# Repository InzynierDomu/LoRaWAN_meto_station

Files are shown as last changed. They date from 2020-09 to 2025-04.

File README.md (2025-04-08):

# LoRaWAN meteo station







- [LoRaWAN meto station](#lorawan-meto-station)
  - [About](#about)
  - [Scheme](#scheme)
    - [Part list:](#part-list)
  - [Configuration](#configuration)
  - [IDE](#ide)
  - [Software upload](#software-upload)

## About
End device to measure air temperature, humidity, pressure, and light intense, and send to TTN. More information for this project you will find in this [note](http://www.inzynierdomu.pl/lora-i-lorawan-czesc-3/)

<div align="center">
<h2>Support</h2>

<p>If any of my projects have helped you in your work, studies, or simply made your day better, you can buy me a coffee. <a href="https://buycoffee.to/inzynier-domu" target="_blank">Postaw mi kawę na buycoffee.to</a></p>
</div>

## Scheme

### Part list:
* U1 Arduino MKR 1300
To board must be connected BME280 and DS18B20. 
## Configuration
Before config this project, prepare an account on TheThingsNetwor. All described [here](http://www.inzynierdomu.pl/lora-i-lorawan-czesc-2/)
Need add device on TTN console to get credentials. Put necessary keys in Config.h file.
To decode information, on TTN use JS formatter ttn_decoder.js.
## IDE
The project is prepared for the Platform IO environment. A video on how to install such an environment can be watched on this [video](https://youtu.be/Em9NuebT2Kc)
## Software upload 
The board may not be programmable during sleep. You should then press the reset button on the board twice quickly. It should appear on a different port and can be programmed.

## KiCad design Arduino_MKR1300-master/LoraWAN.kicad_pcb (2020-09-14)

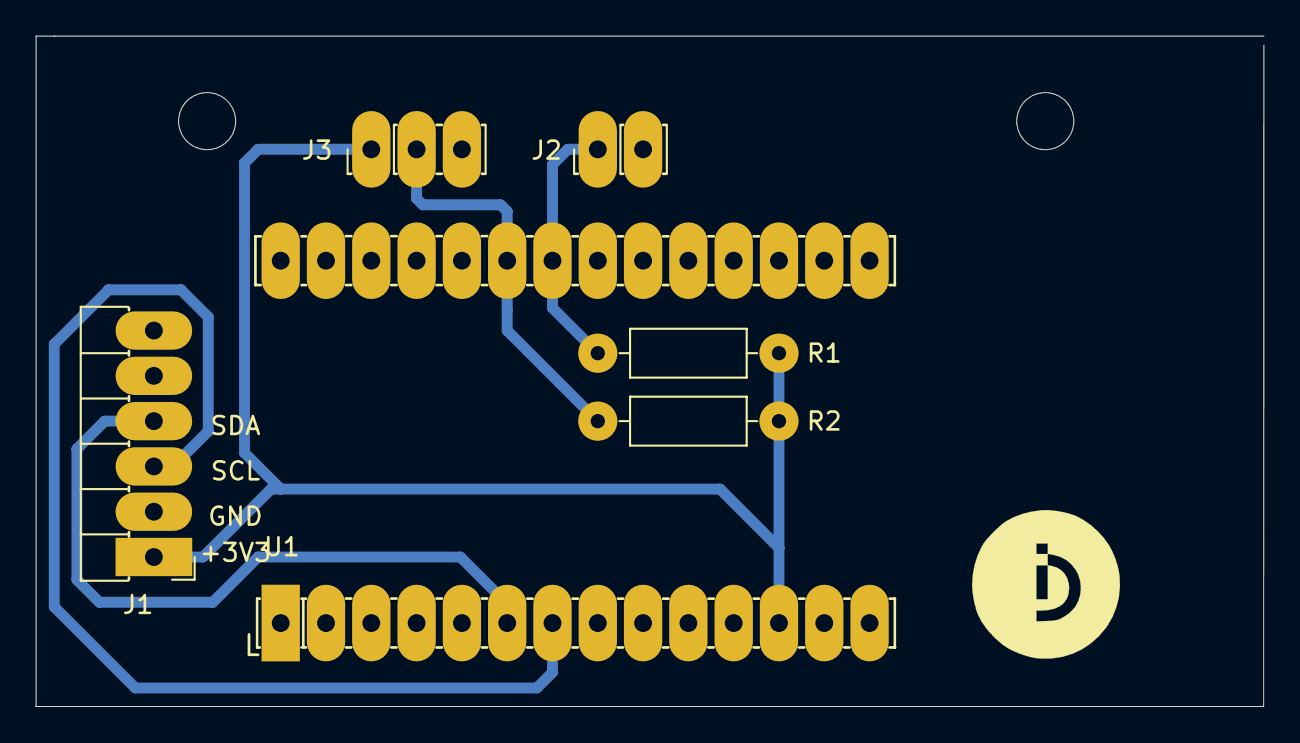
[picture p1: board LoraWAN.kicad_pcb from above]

Board: 2 copper layers, 68.8 x 37.6 mm, 6 parts (0 on the bottom side), 6 nets.

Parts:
J1: Conn_01x06_Male; PinHeader_1x06_P2.54mm_Horizontal_Oval_NoPinSilk
J2: Conn_01x02_Male; PinHeader_1x02_P2.54mm_Vertical_PAD
J3: Conn_01x03_Male; PinHeader_1x03_P2.54mm_Vertical_PAD
R1, R2: 10k; R_Axial_DIN0207_L6.3mm_D2.5mm_P10.16mm_Horizontal_PAD
U1: Ardiuno_MKR1300; Arduino_MKR1300_Oval

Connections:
GND: J1.2, J2.2, J3.3, U1.11
unnamed: J2.1, R1.2, U1.22
unnamed: J3.2, R2.2, U1.23
SCL: J1.3, U1.7
SDA: J1.4, U1.6
VCC: J1.1, J3.1, R1.1, R2.1, U1.12

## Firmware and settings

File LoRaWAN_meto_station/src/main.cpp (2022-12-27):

/**
 * @file LoRaWAN_meteo_station.ino
 * @brief LoRaWAN meteo station main
 * @author by Szymon Markiewicz
 * @details http://www.inzynierdomu.pl/
 * @date 11-2019
 */

#include "ArduinoLowPower.h"
#include "Config.h"
#include "LoRaWAN.h"
#include "Measurements.h"
#include "Pin_config.h"
#include "Results.h"

#include <Arduino.h>

Measurements m_measurements;
LoRaWAN m_lorawan;
Results m_results;

void setup()
{
  Serial.begin(9600);
  delay(60000); // TODO: test without this

  m_lorawan.setup();
  m_measurements.init_sensors();
}

void loop()
{
  m_measurements.measure(m_results);
  m_lorawan.send_msg_measurements(m_results);
  LowPower.deepSleep(Config::uplink_interval);
}

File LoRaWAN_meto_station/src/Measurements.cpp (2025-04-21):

/**
 * @file Measurements.cpp
 * @brief Sensors handling
 * @author by Szymon Markiewicz
 * @details http://www.inzynierdomu.pl/
 * @date 11-2019
 */

#include "Measurements.h"

#include "Config.h"

Measurements::Measurements()
: m_one_wire(OneWire(Pins::one_wire))
, m_ds_sensor(DS18B20(Pins::one_wire))
{}

void Measurements::init_sensors()
{
  bme_init();
  ds_thermometer_init();
}

void Measurements::measure(Results& results)
{
  results.humidity = get_bme_humidity();
  results.pressure = get_bme_pressure();
  results.temperature_ds = get_ds_temperature();
  results.light_intensity = get_light_measure();
  results.soil_moisture = get_soil_moisture_measure();
}

void Measurements::bme_init()
{
  unsigned status = m_bme_sensor.begin(BME280_ADDRESS_ALTERNATE);
  if (!status)
  {
    Serial.println("Could not find a valid BME280 sensor, check wiring, address, sensor ID!");
    Serial.print("SensorID was: 0x");
    Serial.println(m_bme_sensor.sensorID(), 16);
    Serial.print("        ID of 0xFF probably means a bad address, a BMP 180 or BMP 085\n");
    Serial.print("   ID of 0x56-0x58 represents a BMP 280,\n");
    Serial.print("        ID of 0x60 represents a BME 280.\n");
    Serial.print("        ID of 0x61 represents a BME 680.\n");
    while (1)
      ;
    // TODO: error handling
  }
}

uint8_t Measurements::get_bme_humidity()
{
  return m_bme_sensor.readHumidity();
}

uint16_t Measurements::get_bme_pressure()
{
  return m_bme_sensor.readPressure() / 100;
}

void Measurements::ds_thermometer_init()
{
  Serial.print("Serch thermometer");
  m_one_wire.reset_search();
  while (m_one_wire.search(m_ds_address))
  {
    if (m_ds_address[0] != 0x28)
      continue;

    if (OneWire::crc8(m_ds_address, 7) != m_ds_address[7])
    {
      Serial.println(F("1-Wire bus connection error!"));
      break;
    }

    for (byte i = 0; i < 8; i++)
    {
      Serial.print(F("0x"));
      Serial.print(m_ds_address[i], HEX);

      if (i < 7)
        Serial.print(F(", "));
    }
    Serial.println();
  }
}

float Measurements::get_ds_temperature()
{
  return m_ds_sensor.getTempC();
}

uint16_t Measurements::get_light_measure()
{
  return map(analogRead(Pins::light_sensor), 0, 1023, 0, 100);
}

uint16_t Measurements::get_soil_moisture_measure()
{
  return map(analogRead(Pins::soil_moisture_sensor), 0, 1023, 0, 100);
}

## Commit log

2019-12-06 add low power libary
2020-05-22 add minor stylistic corrections
    [LoRaWAN.cpp, Measurements.cpp, main.cpp]
2020-09-14 Add schem and PCB
    [LoraWAN-B_Cu.gbr, LoraWAN-B_Mask.gbr, LoraWAN-B_Paste.gbr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]
2020-09-14 add Node_RED flow
2022-12-27 fix naming in lorawan part
    [LoRaWAN.cpp, main.cpp]
